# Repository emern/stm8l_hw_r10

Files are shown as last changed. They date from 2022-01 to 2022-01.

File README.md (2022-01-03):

# stm8l_hw_r10

## About

Project for a simple breakout board for STMicroelectronics STM8L151C2T6 ultra low-power microcontroller designed with KiCAD version 5.1.3.

## Features

This breakout has the following features:

* Induvidual 5v and 3.3v power bus enable/disable
* USB 2.0 Type-C serial interface
* ST Link programming header
* Full GPIO pinout
* External RTC over I2C (DS1307Z)
* Power and Status LED's
* 5v-12v main power inputs
* M2.5 screw mounting holes

## Requirements

* KiCAD 5.1.3
* [FTDI drivers needed for USB-serial interface](https://ftdichip.com/drivers/)
* Serial monitor such as [PuTTY](https://www.putty.org/)
* [Example Firmware](https://github.com/emern/stm8l_fw_r10)

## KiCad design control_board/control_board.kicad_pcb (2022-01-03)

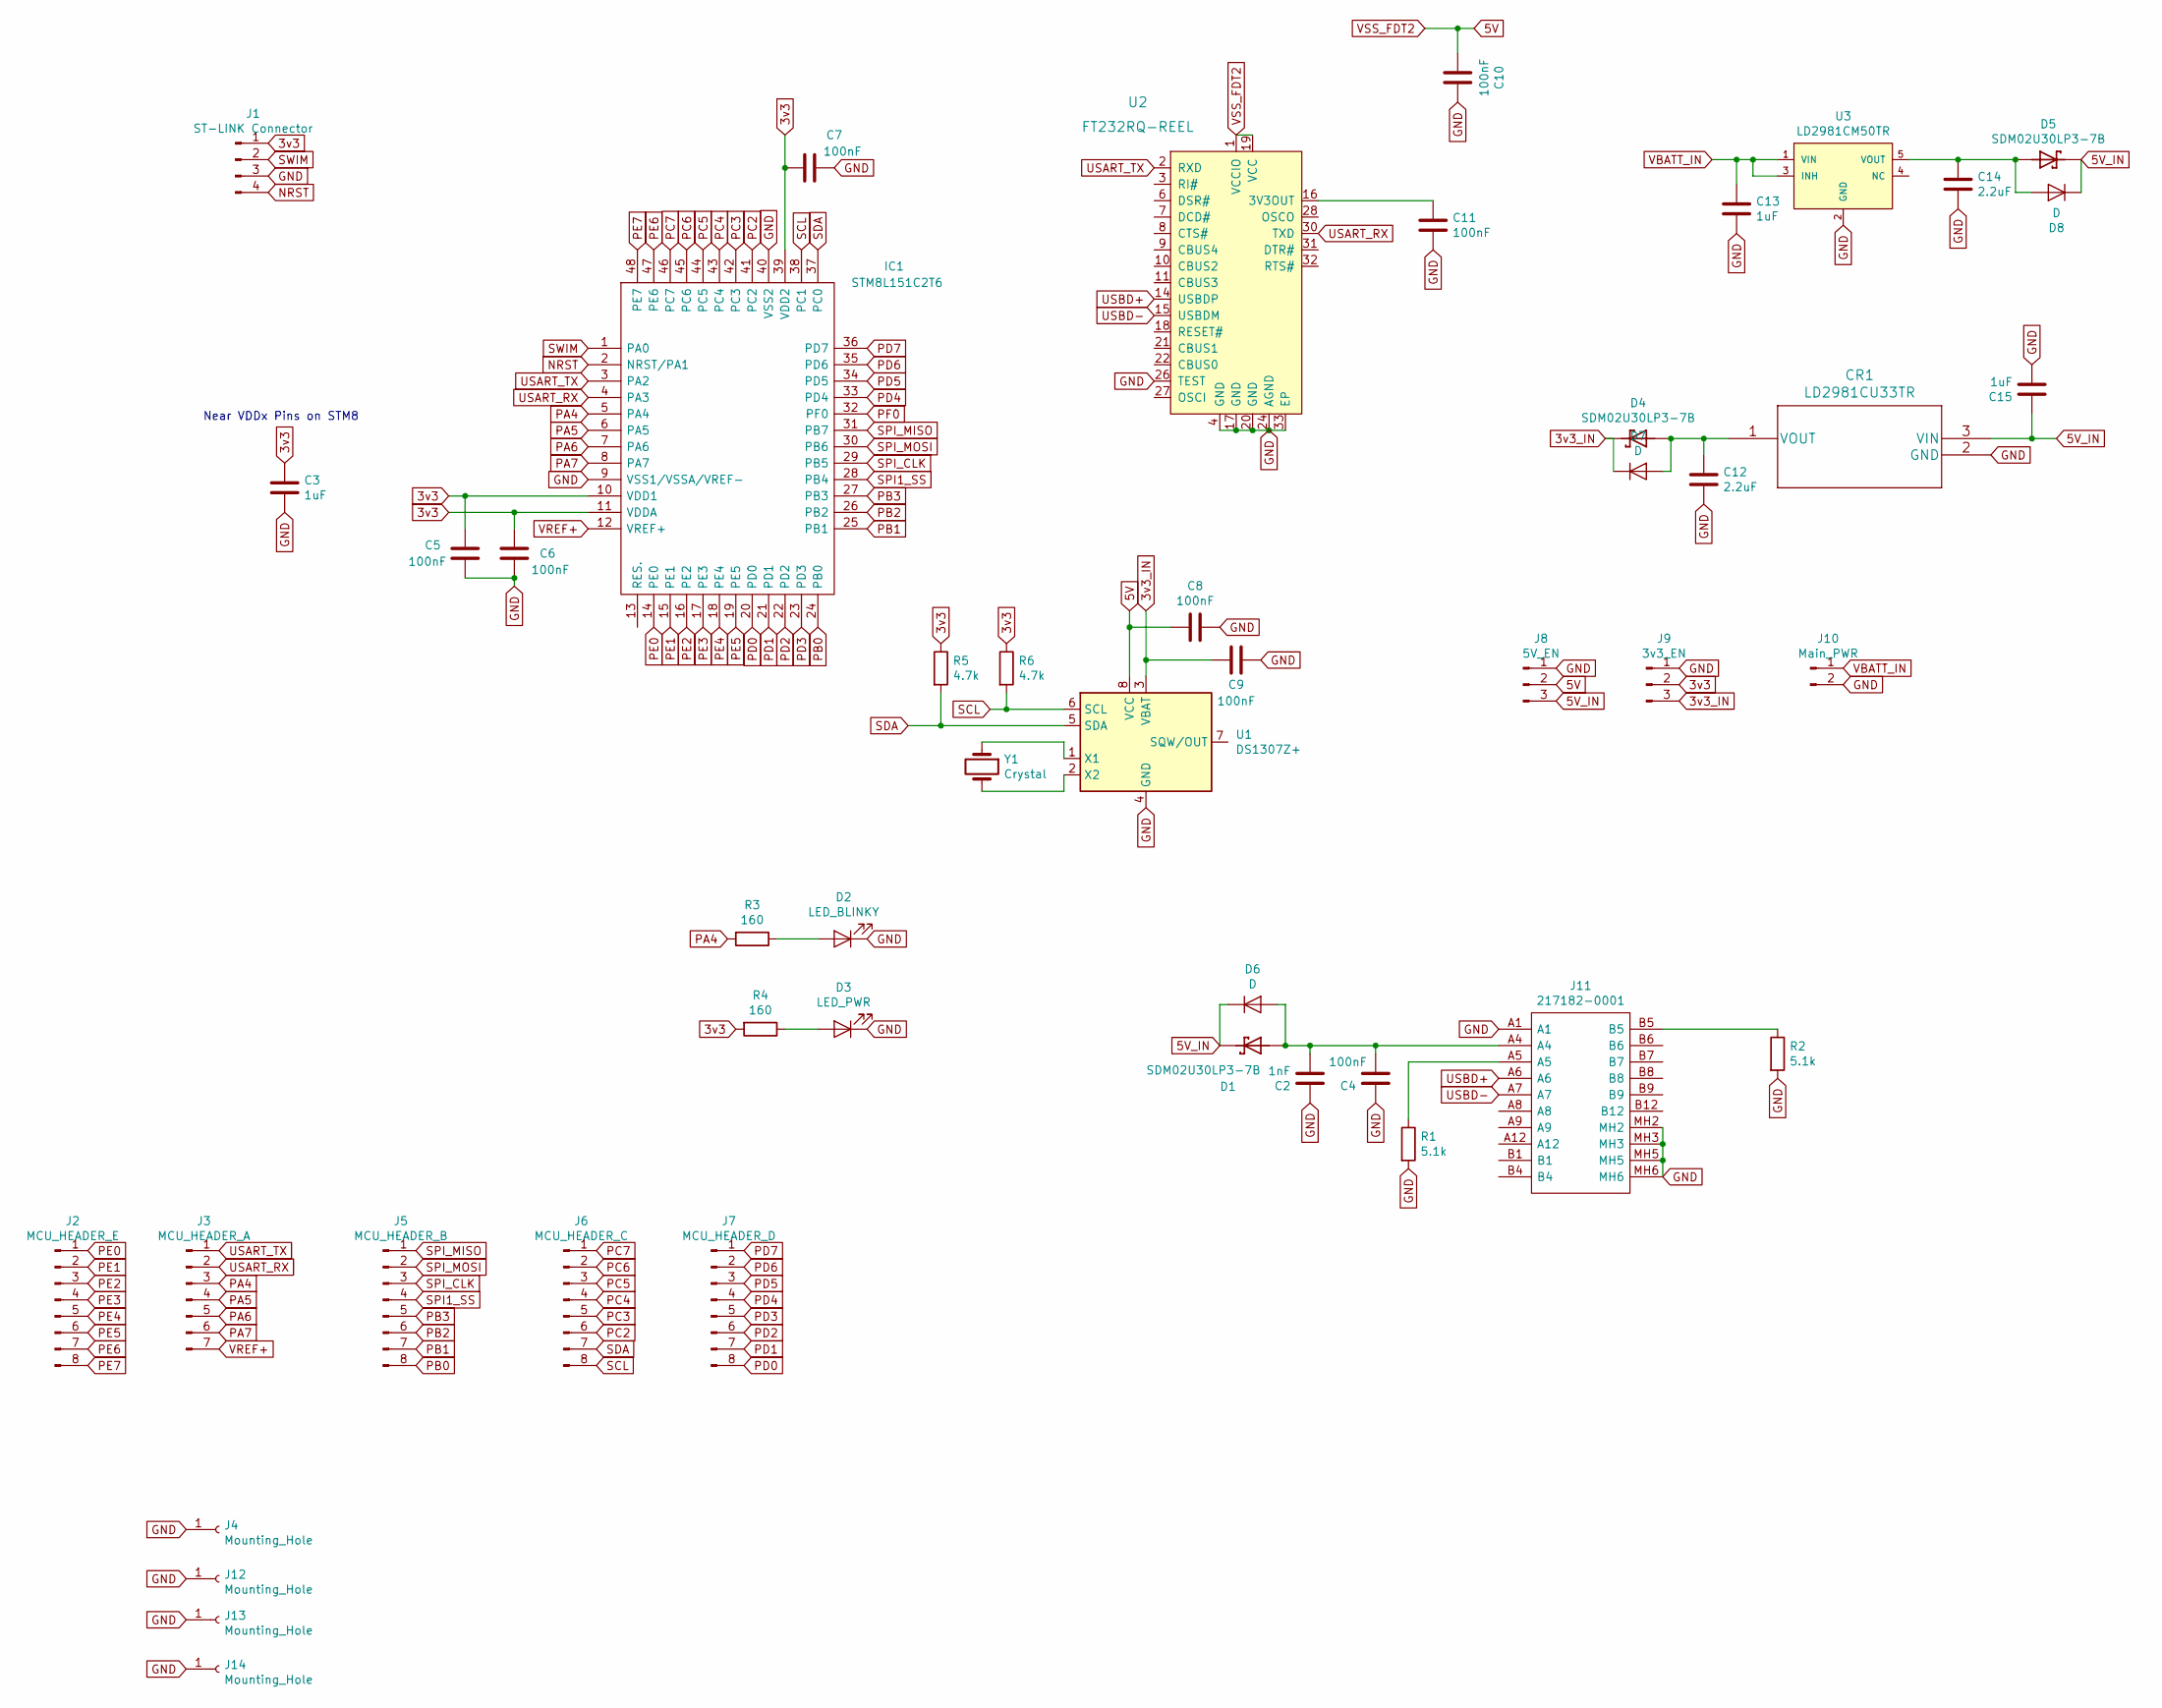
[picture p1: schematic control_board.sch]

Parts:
C2: 1nF; C_0805_2012Metric
C3, C13, C15: 1uF; C_1206_3216Metric
C4, C5, C6, C7, C8, C9, C10, C11: 100nF; C_0805_2012Metric
C12, C14: 2.2uF; C_0805_2012Metric
CR1: LD2981CU33TR; SOT-89-3
D1, D4, D5: SDM02U30LP3-7B; DIODFN62X32X35-2N; PARTREV 5
D2: LED_BLINKY; LED_0402_1005Metric
D3: LED_PWR; LED_0402_1005Metric
D6, D7, D8: D; D_0603_1608Metric
IC1: STM8L151C2T6; LQFP-48_7x7mm_P0.5mm; Manufacturer_Part_Number STM8L151C6T6; Mouser Part Number 511-STM8L151C6T6
J1: ST-LINK Connector; PinHeader_1x04_P2.54mm_Vertical
J2: MCU_HEADER_E; PinHeader_1x08_P2.54mm_Vertical
J3: MCU_HEADER_A; PinHeader_1x07_P2.54mm_Vertical
J4, J12, J13, J14: Mounting_Hole; MountingHole_2.7mm_M2.5_Pad
J5: MCU_HEADER_B; PinHeader_1x08_P2.54mm_Vertical
J6: MCU_HEADER_C; PinHeader_1x08_P2.54mm_Vertical
J7: MCU_HEADER_D; PinHeader_1x08_P2.54mm_Vertical
J8: 5V_EN; PinHeader_1x03_P2.54mm_Vertical
J9: 3v3_EN; PinHeader_1x03_P2.54mm_Vertical
J10: Main_PWR; PinHeader_1x02_P2.54mm_Vertical
J11: 217182-0001; 2171820001; Manufacturer_Part_Number 217182-0001; Mouser Part Number 538-217182-0001
R1, R2: 5.1k; R_1206_3216Metric
R3, R4: 160; R_1206_3216Metric
R5, R6: 4.7k; R_0402_1005Metric
U1: DS1307Z+; SOIC-8_3.9x4.9mm_P1.27mm
U2: FT232RQ-REEL; QFN-32-1EP_5x5mm; MPN FT232RQ-REEL; Digi-Key_PN 768-1008-1-ND
U3: LD2981CM50TR; SOT-23-5
Y1: Crystal; Crystal_SMD_3215-2Pin_3.2x1.5mm

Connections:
3v3: C3.1, C5.2, C6.1, C7.1, IC1.10 (VDD1), IC1.11 (VDDA), IC1.39 (VDD2), J1.1, J9.2, R4.2, R5.1, R6.1
3v3_IN: C9.2, D4.C, D7.1 (K), J9.3, U1.3 (VBAT)
5V: C8.2, C10.2, J8.2, U1.8 (VCC), U2.1 (VCCIO), U2.19 (VCC)
5V_IN: C15.1, CR1.3 (VIN), D1.C, D5.C, D6.1 (K), D8.1 (K), J8.3
GND: C2.1, C3.2, C4.1, C5.1, C6.2, C7.2, C8.1, C9.1, C10.1, C11.2, C12.2, C13.2, C14.2, C15.2, CR1.2 (GND), D2.1 (K), D3.1 (K), IC1.9 (VSS1/VSSA/VREF-), IC1.40 (VSS2), J1.3, J4.1, J8.1, J9.1, J10.2, J11.A1, J11.MH2, J11.MH3, J11.MH5, J11.MH6, J12.1, J13.1, J14.1, R1.2, R2.2, U1.4 (GND), U2.4 (GND), U2.17 (GND), U2.20 (GND), U2.24 (AGND), U2.26 (TEST), U2.33 (EP), U3.2 (GND)
NRST: IC1.2 (NRST/PA1), J1.4
unnamed: C2.2, C4.2, D1.A, D6.2 (A), J11.A4
unnamed: C11.1, U2.16 (3V3OUT)
unnamed: C12.1, CR1.1 (VOUT), D4.A, D7.2 (A)
unnamed: C14.1, D5.A, D8.2 (A), U3.5 (VOUT)
unnamed: D2.2 (A), R3.1
unnamed: D3.2 (A), R4.1
unnamed: J11.A5, R1.1
unnamed: J11.B5, R2.1
unnamed: U1.1 (X1), Y1.1
unnamed: U1.2 (X2), Y1.2
PA4: IC1.5 (PA4), J3.3, R3.2
PA5: IC1.6 (PA5), J3.4
PA6: IC1.7 (PA6), J3.5
PA7: IC1.8 (PA7), J3.6
PB0: IC1.24 (PB0), J5.8
PB1: IC1.25 (PB1), J5.7
PB2: IC1.26 (PB2), J5.6
PB3: IC1.27 (PB3), J5.5
PC2: IC1.41 (PC2), J6.6
PC3: IC1.42 (PC3), J6.5
PC4: IC1.43 (PC4), J6.4
PC5: IC1.44 (PC5), J6.3
PC6: IC1.45 (PC6), J6.2
PC7: IC1.46 (PC7), J6.1
PD0: IC1.20 (PD0), J7.8
PD1: IC1.21 (PD1), J7.7
PD2: IC1.22 (PD2), J7.6
PD3: IC1.23 (PD3), J7.5
PD4: IC1.33 (PD4), J7.4
PD5: IC1.34 (PD5), J7.3
PD6: IC1.35 (PD6), J7.2
PD7: IC1.36 (PD7), J7.1
PE0: IC1.14 (PE0), J2.1
PE1: IC1.15 (PE1), J2.2
PE2: IC1.16 (PE2), J2.3
PE3: IC1.17 (PE3), J2.4
PE4: IC1.18 (PE4), J2.5
PE5: IC1.19 (PE5), J2.6
PE6: IC1.47 (PE6), J2.7
PE7: IC1.48 (PE7), J2.8
PF0: IC1.32 (PF0)
SCL: IC1.38 (PC1), J6.8, R6.2, U1.6 (SCL)
SDA: IC1.37 (PC0), J6.7, R5.2, U1.5 (SDA)
SPI1_SS: IC1.28 (PB4), J5.4
SPI_CLK: IC1.29 (PB5), J5.3
SPI_MISO: IC1.31 (PB7), J5.1
SPI_MOSI: IC1.30 (PB6), J5.2
SWIM: IC1.1 (PA0), J1.2
USART_RX: IC1.4 (PA3), J3.2, U2.30 (TXD)
USART_TX: IC1.3 (PA2), J3.1, U2.2 (RXD)
USBD+: J11.A6, U2.14 (USBDP)
USBD-: J11.A7, U2.15 (USBDM)
VBATT_IN: C13.1, J10.1, U3.1 (VIN), U3.3 (INH)
VREF+: IC1.12 (VREF+), J3.7

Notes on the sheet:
Near VDDx Pins on STM8

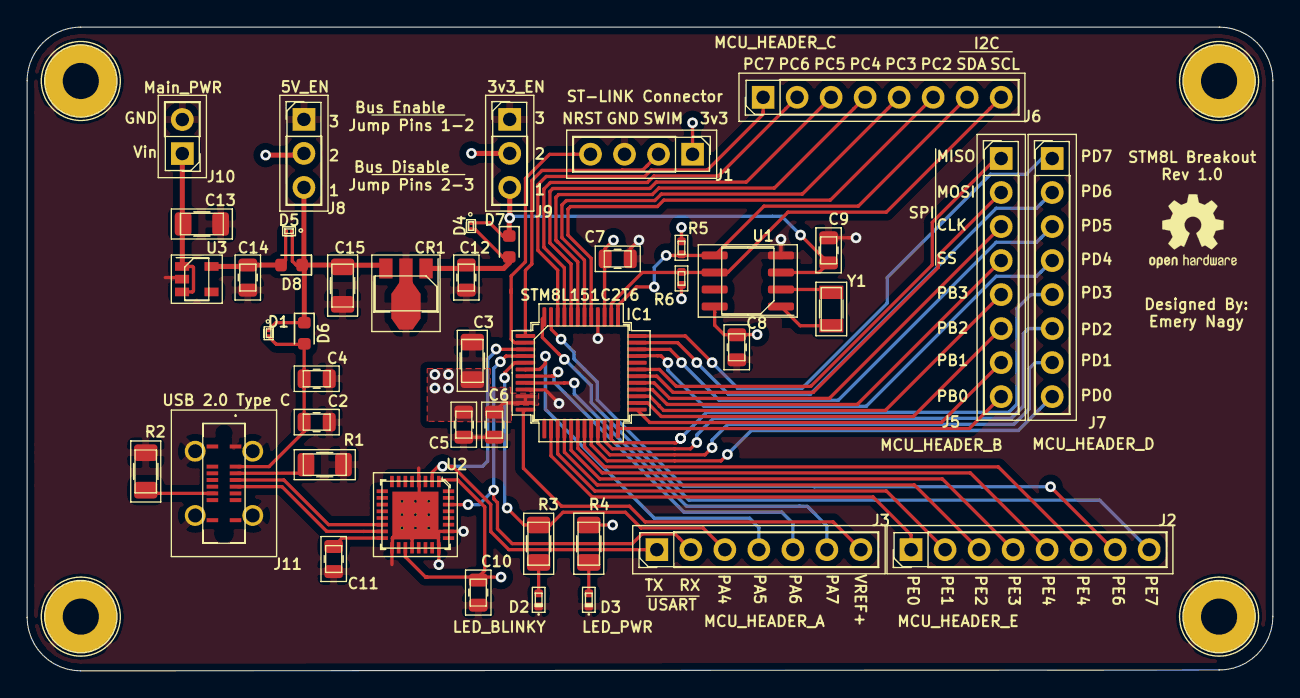
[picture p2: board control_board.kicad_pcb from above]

Board: 4 copper layers, 93.0 x 48.1 mm, 48 parts (0 on the bottom side), 59 nets.

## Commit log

2021-11-28 add rev1.0 hardware
    [control_board-B_Cu.gbl, control_board-B_Mask.gbs, control_board-B_Paste.gbp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]
2022-01-03 update main regulator input
    [control_board.kicad_pcb, control_board.sch]
